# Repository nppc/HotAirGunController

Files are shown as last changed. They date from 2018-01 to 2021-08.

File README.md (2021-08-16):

# HotAirGunController
## Controller for Hot Air Gun with 220v heater and 24v fan
You can use Hot Air Desoldering Gun Handle FOR 858 858D 898D 852D Soldering Station Hot-air Rework Station

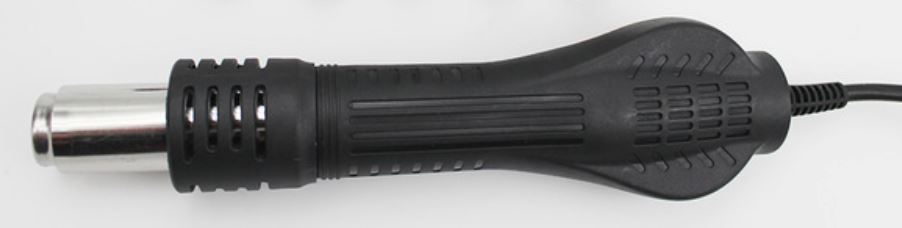
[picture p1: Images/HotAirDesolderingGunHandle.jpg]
HotAirGunHandle


Arduino Nano

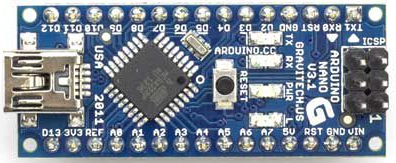
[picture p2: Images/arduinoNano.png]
Nano


i2c OLED 0.91'' (128x32 pixels)

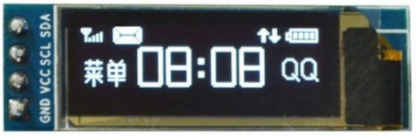
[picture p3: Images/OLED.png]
Oled


and any 240AC Solid State Switch like CPC1998

PCB from oshpark: https://oshpark.com/shared_projects/ofOX8gMQ

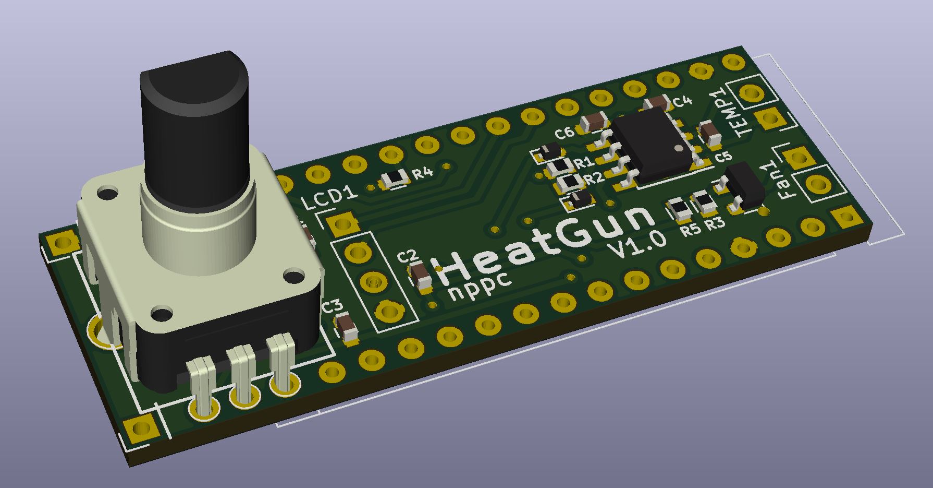
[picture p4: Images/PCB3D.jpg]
PCB 3D


## Workable PIDs
P: 60

I: 3

D: 100

## Alternative PIDs
If your PID control goes crazy, then try these PIDs:

P: 40

I: 3

D: 30

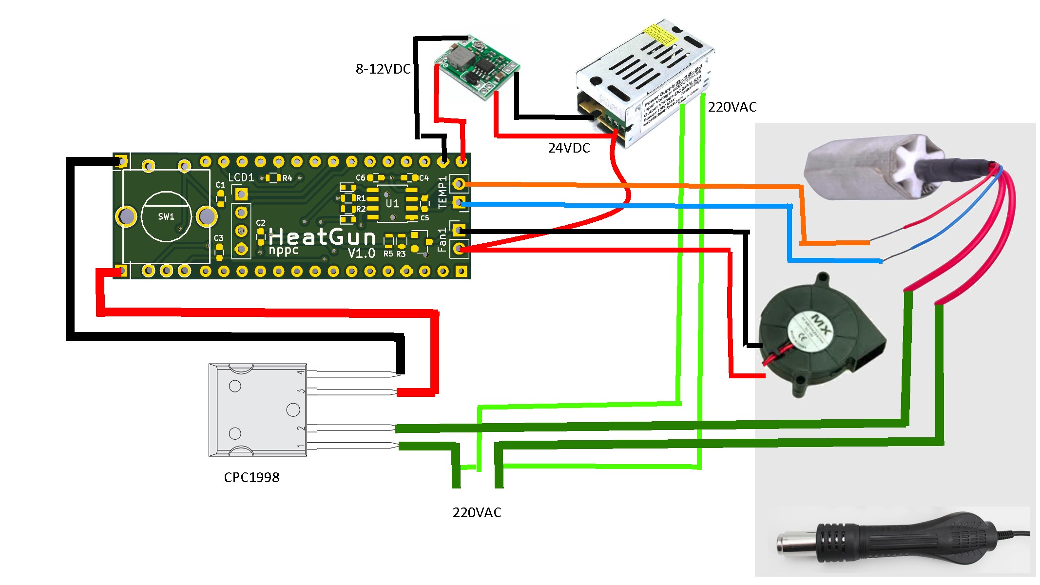
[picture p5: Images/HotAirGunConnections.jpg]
Connections


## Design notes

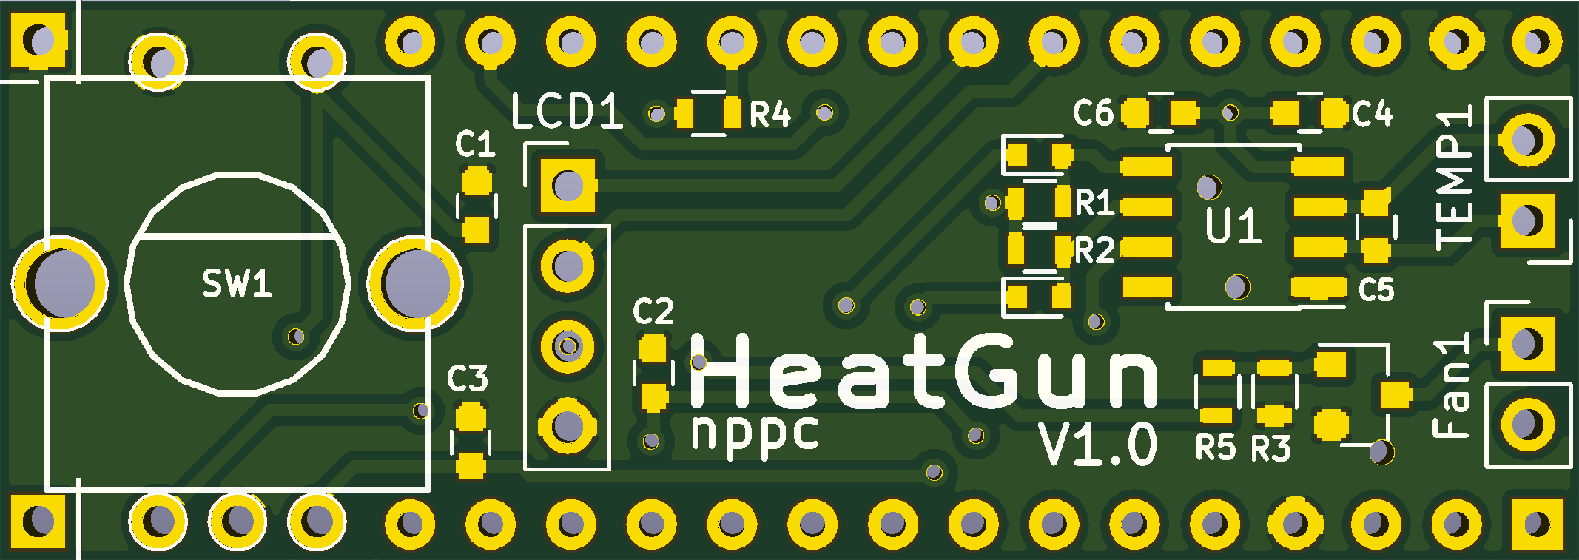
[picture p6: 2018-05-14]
Images/BarePCB3D.png

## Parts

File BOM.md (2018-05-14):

## Bill of Materials

Symbol | Component | Package | Mouser Part No
---- | ------------ | ------------ | ------------
U1 | MAX31855K | SOIC8 | 700-MAX31855KASA+
Q2 | SI2308 or similar | SOT23 | 781-SI2308BDS-E3
R1 |  10K | SMD 0603 | 603-RC0603FR-0710KL
R2 |  10K | SMD 0603 | 603-RC0603FR-0710KL
R3 |  10K | SMD 0603 | 603-RC0603FR-0710KL
R4 |  680 | SMD 0603 | 603-RC0603FR-10680RL
R5 |  100 | SMD 0603 | 603-RC0603FR-07100RL
C1 | 10n-40n | SMD 0603 | 710-885012206016
C2 | 10n-40n | SMD 0603 | 710-885012206016
C3 | 10n-40n | SMD 0603 | 710-885012206016
C4 | 10uf | SMD 0603 | 963-JMK107BJ106MA-T
C5 | 10n | SMD 0603 | 710-885012206014
C6 | 100n | SMD 0603 | 81-GCM188R71E104KA7D
D1 | 1N4148W | SMD SOD-523 | 512-1N4148WT
D2 | 1N4148W | SMD SOD-523 | 512-1N4148WT
SW1 | Rotary Encoder EC11 | | Ebay, Aliexpress or Banggood 
Display | OLED 128x32 with I2c | | Ebay, Aliexpress or Banggood 
SSD | CPC1998 | i4-PAC | 849-CPC1998J

Please note, SSD relay is not mounted on PCB. It should be connected with wires to the Heat- Heat+ pins (behind rotary encoder).

You also need to have 24v power supply for ventilator. Something like this: https://www.aliexpress.com/item/Mini-Size-DC-24V-Power-Supply-Switching-Lighting-Driver-Transformer-100-240V-AC-to-DC24V-SMPS/32818299879.html

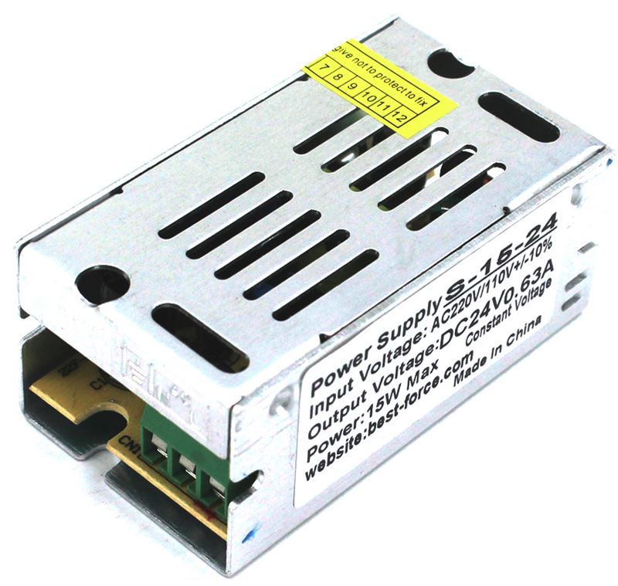
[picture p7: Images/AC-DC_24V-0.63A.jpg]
AC/DC 24V


And for powering Arduino you will need DC/DC converter. Something like this:
https://www.aliexpress.com/item/Free-Shipping-1PCS-XM1584-Ultra-small-size-DC-DC-step-down-power-supply-module-3A-adjustable/32251969850.html

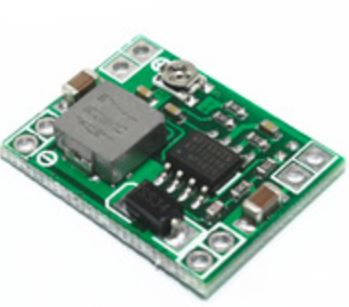
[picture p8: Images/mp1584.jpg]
MP1584EN


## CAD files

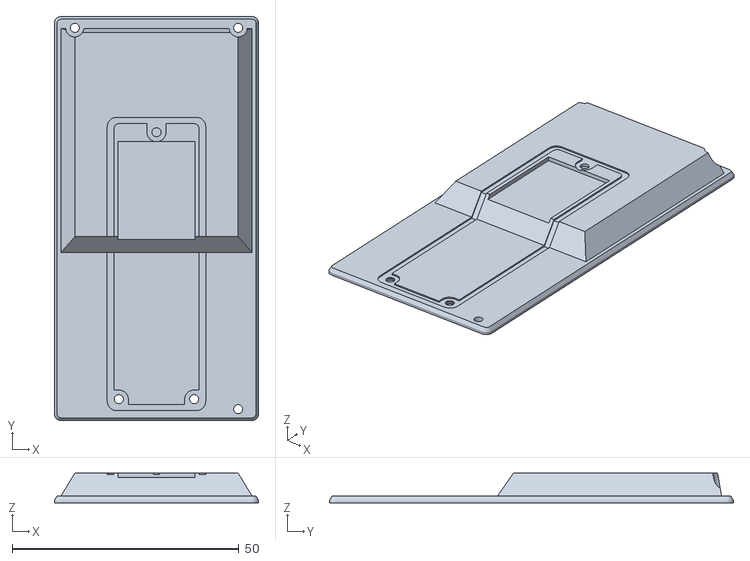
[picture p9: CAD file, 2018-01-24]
SCAD/Middle.stl
45.0 x 89.0 x 6.50

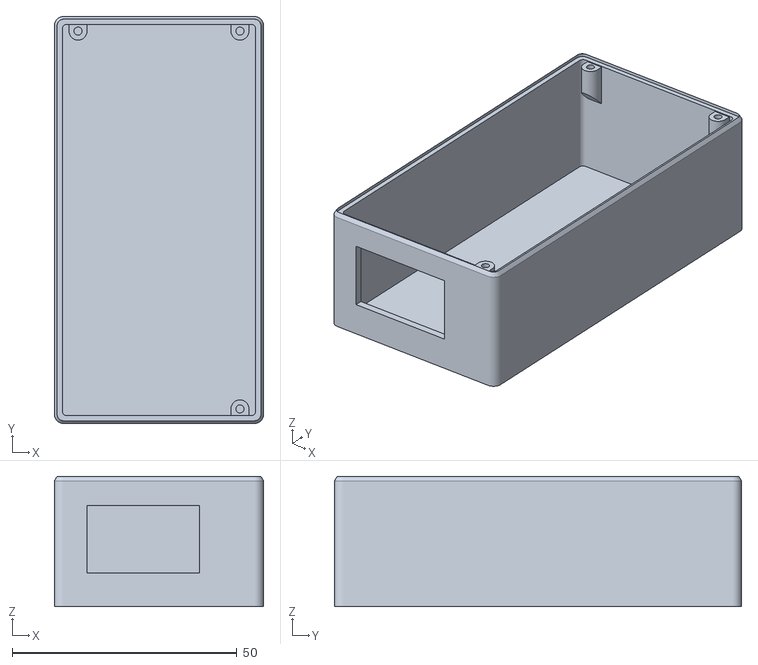
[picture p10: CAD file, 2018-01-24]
SCAD/bottom.stl
46.5 x 90.5 x 29.0

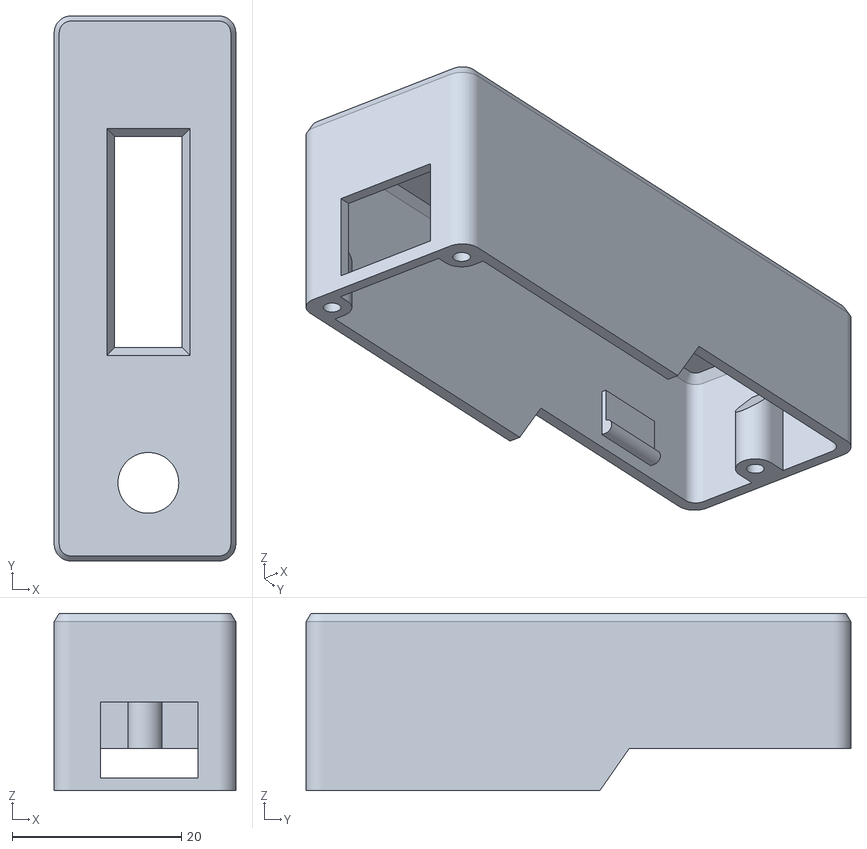
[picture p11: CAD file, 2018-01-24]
SCAD/Box.stl
21.5 x 64.5 x 21.0

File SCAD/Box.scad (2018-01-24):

$fn=50;

//Box();

/*
difference(){
    translate([0,10,-10.75])middlePlate();
    translate([8.3,-29.8,0]){
        cylinder(d=2,h=30,center=true);
        translate([0,0,-11.5])cylinder(d1=5,d2=2,h=2,center=true);
    }
    translate([-8.3,-29.8,0]){
        cylinder(d=2,h=30,center=true);
        translate([0,0,-11.5])cylinder(d1=5,d2=2,h=2,center=true);
    }
    translate([0,29,0])cylinder(d=2,h=11.8,center=true);
    translate([0.1,0,-0.3])Box();
    translate([-0.1,0,-0.3])Box();
    translate([0,-0.1,-0.3])Box();
    //translate([0,0.1,-0.3])Box();
}
*/
translate([0,10,-26])bottomPart();
//translate([-3.5,6,-25])color("GRAY")ACDC24V();

module Box(){
difference(){
    union(){
        difference(){
            union(){
                generalBox(21.5,64.5,21,4);
            }
            translate([0,0,-0.7])generalBox(19,62,20,2.6);

            // cutout for PowerJack
            translate([-17,-11,0.5])rotate([90,0,0])cylinder(d=11,h=30);

            // cutout for encoder pin
            translate([0.4,-23,9]){
                cylinder(d=7.2,h=20);
                translate([6,0,0])cube([2,4,3.5], center=true);
            }

            // Cutout for USB
            translate([0.5,-35,-4])cube([11.5,10,9], center=true);

        }
        // frame for OLED
        translate([0.4,-23+15+25/2+1,9.4])cube([10,27,1], center=true);
        
        // PCB holders
        translate([9,20,9.2-12]){
            rotate([90,0,0])cylinder(d=1.5,h=8,center=true);
            translate([0,-4,-0.75])cube([1,8,5]);
        }
        translate([-9,20,9.2-12]){
            rotate([90,0,0])cylinder(d=1.5,h=8,center=true);
            translate([-1,-4,-0.75])cube([1,8,5]);
        }
   }
    // cutout for OLED
    translate([0.4,-23+15+25/2+1,9]){
        
        cube([8,25,5], center=true);
        hull(){
            translate([0,0,3])cube([11,28,0.1], center=true);
            translate([0,0,2])cube([8,25,3], center=true);
        }
    }
    translate([0,10,-10.75])translate([-43/2,-8,0])DCDC_cover_part(43,50);

}
translate([8.3,-29.8,-5])case_mountinghole_corner();
translate([-8.3,-29.8,-5])rotate([0,0,-90])case_mountinghole_corner();
translate([0,29,0])rotate([0,0,180])case_mountinghole();

}



module generalBox(sx,sy,sz,diam){
    hull(){
        translate([(sx-diam)/2,(sy-diam)/2,0])generalBoxCylinder(sz,diam);
        translate([(-sx+diam)/2,(sy-diam)/2,0])generalBoxCylinder(sz,diam);
        translate([(sx-diam)/2,-(sy-diam)/2,0])generalBoxCylinder(sz,diam);
        translate([-(sx-diam)/2,-(sy-diam)/2,0])generalBoxCylinder(sz,diam);
    }
}

module generalBoxCylinder(hght,diam){
    cylinder(d=diam, h=hght-1,center=true);
    translate([0,0,(hght-1)/2])cylinder(d1=diam,d2=diam-1.2, h=1);
}

module case_mountinghole(){
    rotate([0,180,0])difference(){
        hull(){
            cylinder(d=4, h=10, center=true);
            translate([0,-2,0])cube([4,2,10], center=true);
        }
        translate([0,0,3])cylinder(d=1.8, h=9, center=true);
        translate([0,2,-8])rotate([45,0,0])cube([15,15,10], center=true);
    }
}

module case_mountinghole_corner(){
     rotate([0,180,0])difference(){
         hull(){
             cylinder(d=4, h=10, center=true);
             translate([0,-1,0])cube([4,2,10], center=true);
             translate([-1,0,0])cube([2,4,10], center=true);
         }
         translate([0,0,3])cylinder(d=1.8, h=8, center=true);
         translate([0,2,-8])rotate([45,0,-45])cube([15,15,10], center=true);
         // cut the corner
         translate([-2,-2,0])rotate([0,0,-45])cube([4,2,11], center=true);
     }
 }

module DCDC_cover_part(x,y){
    hull(){
        translate([0,0,-0.5])cube([x,y,0.5]);
        translate([3.5,4,4.75])cube([x-7,y-5,1]);
    }
}

module middlePlate(){
    difference(){
        union(){
            translate([0,0,-0.5])generalBox(36+7+2,87+2,1.5,3);
            translate([-43/2,-8,0])DCDC_cover_part(43,50);
            
        }
        translate([-43/2+1.5,-8+1.5,-1])DCDC_cover_part(40,46);
        translate([0,2,5.2+0.6])cube([17,30,2],center=true);

        translate([18,42,5.75])cylinder(d=4,h=10, center=true);
        translate([-18,42,5.75])cylinder(d=4,h=10, center=true);

        translate([18,42,0])cylinder(d=2,h=10, center=true);
        translate([-18,42,0])cylinder(d=2,h=10, center=true);
        translate([18,-42,0])cylinder(d=2,h=10, center=true);
    }
    //translate([-43/2,40,0])cube([3,3,3],center=true);
}

module bottomPart(){
    difference(){
        translate([0,0,0])generalBox(36+7+2+1.5,87+2+1.5,29,4);
        translate([0,0,1])generalBox(36+7,87,29,2);
        translate([0,0,14.8])generalBox(36+7+2+0.3,87+2+0.3,2,3);
        translate([-3.5,-50,1])cube([25,20,15],center=true);
        translate([16,50,0])rotate([90,0,0])cylinder(d=5.5,h=30);
    }
    translate([18,42,9.1])rotate([180,0,0])case_mountinghole();
    translate([-18,42,9.1])rotate([180,0,0])case_mountinghole();
    translate([18,-42,9.1])rotate([180,0,180])case_mountinghole();
}

module ACDC24V(){
    cube([36,77,27], center=true);
}

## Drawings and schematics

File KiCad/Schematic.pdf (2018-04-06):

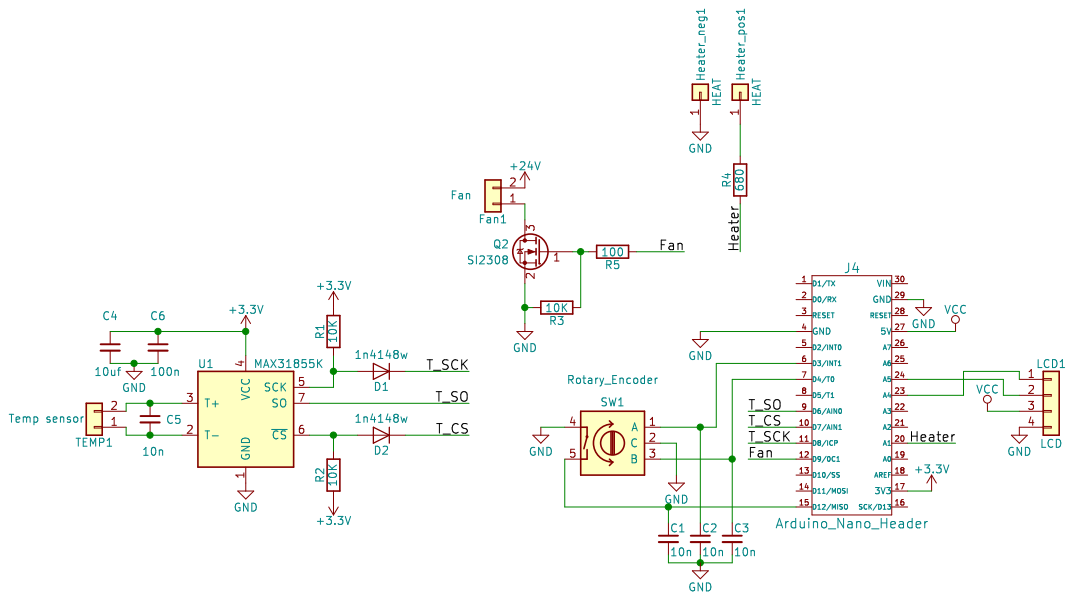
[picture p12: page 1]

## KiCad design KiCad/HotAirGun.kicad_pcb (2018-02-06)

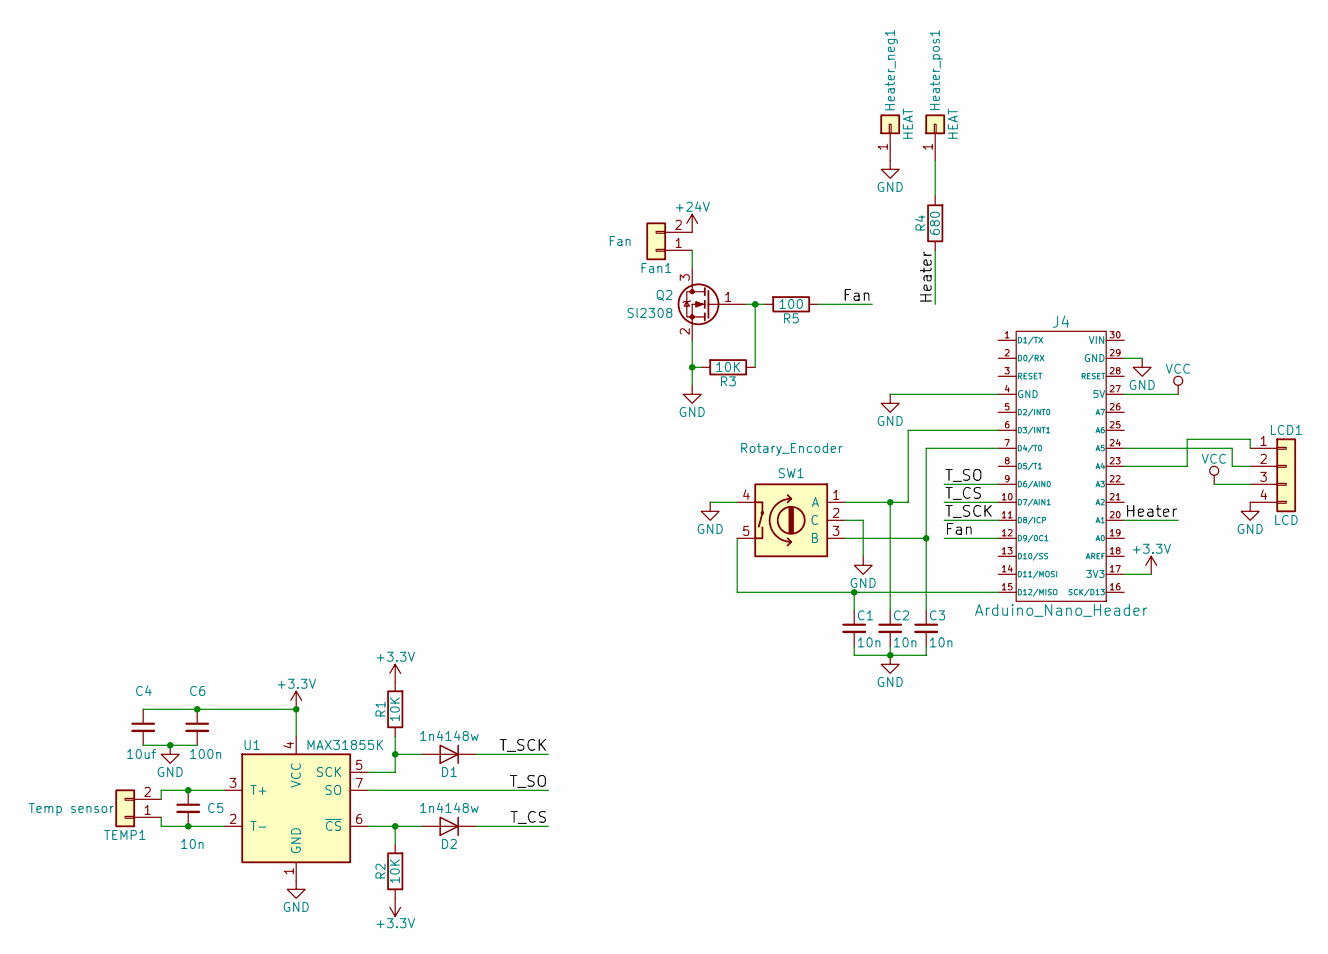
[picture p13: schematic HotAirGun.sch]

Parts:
C1, C2, C3, C5: 10n; C_0603
C4: 10uf; C_0603
C6: 100n; C_0603
D1, D2: 1n4148w; D_SOD-523
Fan1: Fan; Pin_Header_Straight_1x02_Pitch2.54mm
Heater_neg1: HEAT; Pin_Header_Angled_1x01_Pitch2.54mm
Heater_pos1: HEAT; Pin_Header_Angled_1x01_Pitch2.54mm
J4: Arduino_Nano_Header; Arduino_Nano
LCD1: LCD; Pin_Header_Straight_1x04_Pitch2.54mm
Q2: SI2308; SOT-23
R1, R2, R3: 10K; R_0603
R4: 680; R_0603
R5: 100; R_0603
SW1: Rotary_Encoder; SF-ROTARY-ENCODER
TEMP1: Temp sensor; Pin_Header_Straight_1x02_Pitch2.54mm
U1: MAX31855K; SOIC-8_3.9x4.9mm_Pitch1.27mm

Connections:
+3V3: C4.1, C6.1, J4.17 (3V3), R1.2, R2.1, U1.4 (VCC)
/Fan: J4.12 (D9/0C1), R5.1
/Heater: J4.20 (A1), R4.1
/T_CS: D2.1 (K), J4.10 (D7/AIN1)
/T_SCK: D1.1 (K), J4.11 (D8/ICP)
/T_SO: J4.9 (D6/AIN0), U1.7 (SO)
GND: C1.2, C2.2, C3.2, C4.2, C6.2, Heater_neg1.1, J4.4 (GND), J4.29 (GND), LCD1.4, Q2.2 (S), R3.2, SW1.2 (C), SW1.4, U1.1 (GND)
unnamed: C1.1, J4.15 (D12/MISO), SW1.5
unnamed: C2.1, J4.6 (D3/INT1), SW1.1 (A)
unnamed: C3.1, J4.7 (D4/T0), SW1.3 (B)
unnamed: C5.1, TEMP1.2, U1.3 (T+)
unnamed: C5.2, TEMP1.1, U1.2 (T-)
unnamed: D1.2 (A), R1.1, U1.5 (SCK)
unnamed: D2.2 (A), R2.2, U1.6 (~CS~)
unnamed: Fan1.1, Q2.3 (D)
unnamed: Heater_pos1.1, R4.2
unnamed: J4.23 (A4), LCD1.1
unnamed: J4.24 (A5), LCD1.2
unnamed: Q2.1 (G), R3.1, R5.2
VCC: J4.27 (5V), LCD1.3

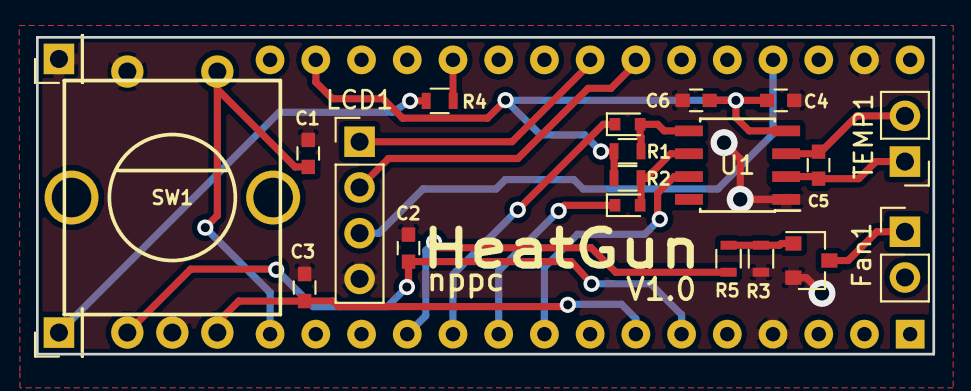
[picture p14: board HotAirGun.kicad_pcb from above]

Board: 2 copper layers, 49.8 x 17.6 mm, 22 parts (1 on the bottom side), 20 nets.

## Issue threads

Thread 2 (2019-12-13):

Problems in compilation

tan45power, 2019-12-13:
Thank you for sharing. I'm a beginner. I encountered some problems during compilation. Is it caused by my lack of library files?Which version of the library file should I use?  Can you give me some advice? At the beginning of compilation, it was prompted that pid_v1 and u8g2 were missing. I did not prompt after downloading and installing from the Internet. What I installed was  Arduino 1.8.10, thank you
'HotAirGunFirmware:141:2: error: 'fan_logo' was not declared in this scope ，HotAirGunFirmware:154:2: error: 'WDT_Init' was not declared in this scope，HotAirGunFirmware.ino:154:2: note: suggested alternative: 'WDT_vect'，
HotAirGunFirmware:172:2: error: 'showMainData' was not declared in this scope，
config:49:3: error: 'WDT_Init' was not declared in this scope，
config.ino:49:3: note: suggested alternative: 'WDT_vect'，
'showMainData' was not declared in this scope，max31855:80:1: error: expected declaration before '}' token.

nppc, 2019-12-13:
I suppose that you did not extracted all files from the archive. Please extract them to one directory named HotAirGunFirmware. Then try to compile again. Use latest versions of libraries (what I think you  doing already)

hansrobothans, 2021-04-14:
我也和tan45power一样遇到了同样的问题
I had the same problem of tan45power

hansrobothans, 2021-04-14:
After modification, I have solved the problem in the program. If you need, you can give me your email and I will send it to you @ @tan45power

nppc, 2021-04-14:
Thanks. You can create a merge request for the changes.

hansrobothans, 2021-04-14:
I will not merge……

zuhair01, 2021-08-15:
do you have a solution!

tan45power, 2021-08-16:
>
>
> 经过修改，我已经解决了程序中的问题。如果你需要，你可以给我你的电子邮件，我会发给你@@tan45power

Thanks.@hansrobothans  gooyyy2@gmail.com , I found that the version provided by @ Dmitry supranov can run in contributors of this project,@zuhair01

nppc, 2021-08-16:
For some reason I can't reproduce your issues. I have Arduino IDE 1.8.12. Could you please explain what steps are you doing?
Please show me all your output from Arduino IDE. Usually the first lines in the errors give the root cause of the issue.

zuhair01, 2021-08-16:
Arduino: 1.8.15 (Windows 10), Board:
C:\Users\xxxxxxx\Downloads\HotAirGunController-master eeeeee\HotAirGunController-master\HotAirGunFirmware\HotAirGunFirmware.ino: In function 'void setup()':

HotAirGunFirmware:141:2: error: 'fan_logo' was not declared in this scope

  fan_logo();

  ^~~~~~~~

C:\Users\xxxxxxx\Downloads\HotAirGunController-master eeeeee\HotAirGunController-master\HotAirGunFirmware\HotAirGunFirmware.ino: In function 'void loop()':

HotAirGunFirmware:154:2: error: 'WDT_Init' was not declared in this scope

  WDT_Init(); // keep system alive

  ^~~~~~~~

C:\Users\xxxxxxx\Downloads\HotAirGunController-master eeeeee\HotAirGunController-master\HotAirGunFirmware\HotAirGunFirmware.ino:154:2: note: suggested alternative: 'WDT_vect'

  WDT_Init(); // keep system alive

  ^~~~~~~~

  WDT_vect

HotAirGunFirmware:172:2: error: 'showMainData' was not declared in this scope

  showMainData();

  ^~~~~~~~~~~~

C:\Users\xxxxxxx\Downloads\HotAirGunController-master eeeeee\HotAirGunController-master\HotAirGunFirmware\config.ino: In function 'void configureParams()':

config:49:3: error: 'WDT_Init' was not declared in this scope

   WDT_Init();

   ^~~~~~~~

C:\Users\xxxxxxx\Downloads\HotAirGunController-master eeeeee\HotAirGunController-master\HotAirGunFirmware\config.ino:49:3: note: suggested alternative: 'WDT_vect'

   WDT_Init();

   ^~~~~~~~

   WDT_vect

C:\Users\xxxxxxx\Downloads\HotAirGunController-master eeeeee\HotAirGunController-master\HotAirGunFirmware\encoder.ino: In function 'void waitUntilButtonReleased()':

encoder:76:4: error: 'WDT_Init' was not declared in this scope

    WDT_Init();

    ^~~~~~~~

C:\Users\xxxxxxx\Downloads\HotAirGunController-master eeeeee\HotAirGunController-master\HotAirGunFirmware\encoder.ino:76:4: note: suggested alternative: 'WDT_vect'

    WDT_Init();

    ^~~~~~~~

    WDT_vect

C:\Users\xxxxxxx\Downloads\HotAirGunController-master eeeeee\HotAirGunController-master\HotAirGunFirmware\max31855.ino: At global scope:

max31855:80:1: error: expected declaration before '}' token

 }

 ^

exit status 1

'fan_logo' was not declared in this scope

This report would have more information with
"Show verbose output during compilation"
option enabled in File -> Preferences.

nppc, 2021-08-16:
Ok. I will try to play with code later today...

пн, 16 авг. 2021 г. в 14:19, zuhair01 ***@***.***>:

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

nppc, 2021-08-16:
Thank you all for the information provided. Compilation issue should be fixed now.

Closed 2021-08-16.

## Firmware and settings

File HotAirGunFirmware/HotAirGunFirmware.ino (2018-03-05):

//#define SOFTRESET	// If your Arduino has broken bootloader (watchdog is not working) then enable this dirty trick or better - flash optiboot to your arduino.
//#define PROTOTYPE	// Prototype version without V1.0 PCB 
//#define DEBUG
//#define SUSPEND_LONGPRESS // Enter Cool down (Suspend mode) when encoder long press while in not safe Temp.
//#define USE_MAGNET_SENSOR

#ifdef PROTOTYPE
	#define FAN_PIN     6 // Pin for controlling fan via PWM
	#define HEATER_PIN  9 // Pin for controlling SSR
	#define MAXSCK_PIN  2
	#define MAXCS_PIN   5
	#define MAXDO_PIN   7
#else
	#define FAN_PIN     9  // Pin for controlling fan via PWM
	#define HEATER_PIN  A1 // Pin for controlling SSR
	#define MAXSCK_PIN  8
	#define MAXCS_PIN   7
	#define MAXDO_PIN   6
#endif
#define LED_PIN      13
#define encoderPinA   3	// Interrupt pin (coupled with capacitor to GND)
#define encoderPinB   4 // Interrupt pin (coupled with capacitor to GND)
#define BUTTON_PIN   12 // Pin for knob button

#ifdef USE_MAGNET_SENSOR
  #define MAGNET_SENSOR_PIN A3
#endif

#ifdef PROTOTYPE
	#define TIMER_MULTIPLIER  8 // if timer has normal (x64) prescaller, then 1
#else
	#define TIMER_MULTIPLIER  1 // if timer has normal (x64) prescaller, then 1
#endif

// some macros
#define mdelay(val) delay(val * TIMER_MULTIPLIER)
#define mmillis() (millis() / TIMER_MULTIPLIER)
#define H_ON   digitalWrite(HEATER_PIN,HIGH);digitalWrite(LED_PIN, HIGH);
#define H_OFF   digitalWrite(HEATER_PIN,LOW);digitalWrite(LED_PIN, LOW);

#include <PID_v1.h>
#include <U8g2lib.h>
#include "encoder.h"
#include <EEPROM.h>
#include "eeprom.h"
#include <avr/wdt.h>
#include "oled.h"


#define PID_WINDOWSIZE 400	// upper limit of PID output
#define PID_ABSTEMPDIFFERENCE 100	// Difference in set and current temperature when PID should not work.
#define PID_P_FACTOR 0.1	//PID values are stored in EEPROM in int format. So, scale them (div) before use.
#define PID_I_FACTOR 0.1	//PID values are stored in EEPROM in int format. So, scale them (div) before use.
#define PID_D_FACTOR 1.0	//PID values are stored in EEPROM in int format. So, scale them (div) before use.

double currentTemp=0;
double setPoint=20;
double outputVal;
#ifdef USE_MAGNET_SENSOR
  int magnetSensorState = 0;
#endif

int pid_P, pid_I, pid_D; // PID values

#ifdef DEBUG
	unsigned long serial_ms = 0;
#endif

unsigned long soft_pwm_millis = mmillis();

int fanSpeed, fanSpeed_actual=0; // signed values. byte type is not working here
unsigned long fanSpeed_millis=0;
int airTemp;
int SafeTemp;	//Safe temperature to enter to the Config
int presetTemp = 20; // variable for storing adjusted temperature

bool suspendMode=0;

int outVal = 0;

//input/output variables passed by reference, so they are updated automatically
PID myPID(&currentTemp, &outputVal, &setPoint, 0, 0, 0, DIRECT); // PID values will be set later

// It is very important to check the temperature all the time.
// Because, if we turn off fan, when heater is still hot, then we can brake the device.
// So, even in config we should monitor temperature and cool down the heater with fan if needed. 

void setup() {
	wdt_disable();

	// mess the timer (millis will be x8 faster)
	// to prevent audible noise from PWM
	// TCCR0B = TCCR0B & 0b11111000 | 0x03; //x64 - default timer speed
#ifdef PROTOTYPE
	TCCR0B = (TCCR0B & 0b11111000) | 0x02; // x8 for pin D6
#else
	// in this case millis() and delay() is not affected
	//TCCR1B = (TCCR1B & 0b11111000) | 0x02; // x8 for pin D9
#endif

  //Heater Off
  H_OFF;
  pinMode(HEATER_PIN, OUTPUT);
  pinMode(LED_PIN, OUTPUT);

#ifdef USE_MAGNET_SENSOR
  pinMode(MAGNET_SENSOR_PIN, INPUT_PULLUP);
#endif 

	// read PID values from EEPROM
	restore_settingsEEPROM();

	// read temperature as soon as possible
	MAX31855_init();
	for(uint8_t i=0;i<50;i++){airTemp = readMAX31855();}	//fill smootharray

	//Set fan speed
	fanControl();
	
	u8g2.begin();
	u8g2.setDrawColor(2);	// Xor is default mode across all sketch.
	u8g2.setFontMode(1);	// Or is default mode
	u8g2.setBitmapMode(1);
	u8g2.setFont(u8g2_font_t0_22_mf);

	#ifdef DEBUG
		Serial.begin(115200);
		Serial.println(F("Startup"));
	#endif
	
	initEncoder();

	// check, if button was pressed while power on (or after reset), then enter to Config mode
	if (rotaryEncRead() == 127){
		// go to config menu
		mdelay(100);
		// check again does we still holding the button?
		if (rotaryEncRead() == 127){configureParams();}
	}

	fan_logo();
	mdelay(2000);

	// we use FACTOR for PID values to get rid of comas in interface.
	myPID.SetTunings((float)pid_P * PID_P_FACTOR,(float)pid_I * PID_I_FACTOR,(float)pid_D * PID_D_FACTOR);
	myPID.SetOutputLimits(0, PID_WINDOWSIZE);	//set PID output range (1/5)

	myPID.SetMode(AUTOMATIC); // turn on PID
	
}

void loop() {
 	// reboot by holding button for 2 seconds...
	WDT_Init();	// keep system alive

	getTemperature();	// updates airTemp variable
	currentTemp = airTemp;	// variable for PID

	// if not suspend
	if(!suspendMode){setPoint = (float)presetTemp;}else{setPoint = 20.0;}
	
	// use PID only when difference is small (to prevent windup of I)
	if(abs(setPoint-currentTemp)<PID_ABSTEMPDIFFERENCE){
		myPID.Compute();
	}else{
		outputVal = (setPoint > currentTemp ? PID_WINDOWSIZE : 0); // ON/OFF control
	}

	if(setPoint>20){doSoftwarePWM((uint16_t)outputVal);}else{H_OFF;soft_pwm_millis=mmillis();}
	
	adjustValues();
	showMainData();

	fanControl();

#ifdef USE_MAGNET_SENSOR
	magnetSensorState = digitalRead(MAGNET_SENSOR_PIN);
	suspendMode = ! magnetSensorState;
#endif  

	// debug 
#ifdef DEBUG
	if (serial_ms+1000 < mmillis()) {
		serial_ms = mmillis();
		Serial.print(F("Set: "));Serial.print(setPoint);
		Serial.print(F(", Actual: "));Serial.print(currentTemp);
		Serial.print(F(", PWM: "));Serial.print(outputVal);
		Serial.print(F(", Fan: "));Serial.print(fanSpeed_actual);

  #ifdef USE_MAGNET_SENSOR
    Serial.print(F(", Magnet: "));Serial.print(magnetSensorState);
  #endif
    Serial.println("");
	}	
#endif	

}

// PWM output
void doSoftwarePWM(uint16_t pwm_val){
	if (soft_pwm_millis+PID_WINDOWSIZE < mmillis()) {
		soft_pwm_millis = mmillis();
		if (pwm_val > 0){H_ON;}	// start of the impulse
	} else if (soft_pwm_millis + pwm_val < mmillis()){H_OFF;}
}


void adjustValues() {
	int val_adjust=0;	// for adjusting temperature or fan speed on the fly
	char encVal = 127;  // signed value - just enter to the loop
	while (encVal == 127) { //loop here while button is pressed (waiting longer than 2 seconds will reset the board (Exit to the init menu).
		encVal = rotaryEncRead();
		if(encVal!=127) {
			val_adjust = encVal;
		}else if(encVal==127){
			H_OFF;	// turn off heater, because we will freeze here for some time...
			#ifdef DEBUG
				Serial.println(F("Button Pressed..."));
			#endif
			waitUntilButtonReleased();
			#ifdef DEBUG
				Serial.println(F("Button Released"));
			#endif
			value_editable++;	// change edit mode
			if(value_editable>2){value_editable=1;}
			value_editable_millis=mmillis();		// start timer for edit time within 3 seconds
		}
	}
	// adjust current temperature or fan speed
	if(val_adjust!=0){
		val_adjust*=10; // adjust in 10's steps
		if(value_editable==1){
			fanSpeed=constrain(fanSpeed+val_adjust,30,100);
		}else if(value_editable==2){
			presetTemp=constrain(presetTemp+val_adjust,20,500);
		}else{
			value_editable=2;
		}
		value_editable_millis=mmillis();
	}
	// reset timer_editable flag if edit time expired
	if(value_editable>0 && value_editable_millis+3000<mmillis()) {value_editable=0;}
}	

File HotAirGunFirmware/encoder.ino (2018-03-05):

// Encoder routines. Uses one Interrupt.

void initEncoder() {    
	pinMode(encoderPinA, INPUT_PULLUP); 
    pinMode(encoderPinB, INPUT_PULLUP); 
    pinMode(BUTTON_PIN, INPUT_PULLUP); 
    attachInterrupt(1, INT_doEncoder, FALLING);  // encoder pin on interrupt 1 - pin 3
}

char rotaryEncRead() {
  noInterrupts();
  char tmp = encoderPos;
  encoderPos=0;  // reset encoder
  interrupts();
  if(!digitalRead(BUTTON_PIN)){tmp=127;} // read button
  return tmp;
}

void INT_doEncoder() {
    // If interrupts come faster than 5ms, assume it's a bounce and ignore
    if (mmillis() - encodermillis > 5) {
        if (!digitalRead(encoderPinB))
            encoderPos++;
        else
            encoderPos--;

		has_encoderChange = HIGH;
        }
    encodermillis = mmillis();
}

// determine if rotary encoder was pressed longer than 2 seconds
/*
bool is_rotaryEncLongPress() {
	 if(digitalRead(BUTTON_PIN)){
		 // button is not pressed
		 encoderLongPressmillis=mmillis();
	 }else{
		 // button is pressed
		 // how long?
		 if((encoderLongPressmillis+2000)<mmillis()){
			 // Long press engaged
			 return true;
			 encoderLongPressmillis=mmillis();	// reset counter
		 }
	 }
	 return false;
}
*/
void waitUntilButtonReleased(){
	// wait until button is depressed
#ifdef SUSPEND_LONGPRESS
	int delaycounter=0;
	while(rotaryEncRead() == 127){
		if(SafeTemp < airTemp || suspendMode){
			WDT_Init();
			mdelay(50);
			delaycounter++;
			if(delaycounter>30){
				// enable/disable cooldown mode
				if(!suspendMode){
					suspendMode=1;
					printSuspend();
				}else{
					suspendMode=0;
					printResume();
				}
				while(rotaryEncRead() == 127){WDT_Init();}
			}
			
		}
	} // keep system alive
#else
	while(rotaryEncRead() == 127){
		if(SafeTemp < airTemp){
			WDT_Init();
		}
	}
#endif
mdelay(50); // wait for noise is gone from button contacts
}

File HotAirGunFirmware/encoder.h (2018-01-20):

volatile char encoderPos = 0;	// accumulate encoder ticks in Interrupt.
volatile bool has_encoderChange = LOW;	// Indicates that Encoder has changed
unsigned long encodermillis = 0;
unsigned long encoderLongPressmillis = 0;
uint8_t value_editable=0;	// Edit Preset temperature or Fan on the fly (0 - nothing editable, 1 - Preset Temp, 2 - Fan)
unsigned long value_editable_millis;

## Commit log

2018-01-15 Testing Heater element
2018-01-15 KiCad project created
    [HotAirGun.kicad_pcb, HotAirGun.sch]
2018-01-20 ThermoCouple controller Breakout board
    [temp.kicad_pcb, temp.sch]
2018-01-20 Add CNC project
    [temp-F.Cu.dxf, temp.kicad_pcb]
2018-01-22 SCAD project.
    [Box.scad, Box.stl, Middle.stl]
2018-01-23 Draft of SCAD is ready
    [Box.scad, Box.stl, Middle.stl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]
2018-01-26 Adjusted PID scalling and other minor issues
    [HotAirGunFirmware.ino]
2018-02-06 Some texts added
    [HotAirGun.kicad_pcb]
2018-02-06 Final adjustments
    [HotAirGun.kicad_pcb]
2018-02-06 Add conditionals for Prototype board and final PCB
2018-03-03 Led pin initialisation
2018-03-04 Safe Temperature added. Some improvements on Startup Fan control
2018-03-05 Added support of magnet sensor at A3 pin
2018-03-05 Timer speed is left unchanged
2018-03-05 Fix bug with config entering
    [encoder.ino]
2018-04-06 A bit faster temperature readings
2018-04-06 Added schematic and 3D model of PCB
    [HotAirGun.sch, temp-F.Cu.dxf, temp.kicad_pcb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]
2018-05-14 BOM created
2021-08-16 fix compilation issue after adding max31855
    [max31855.ino]
2021-08-16 Added link to PCB
